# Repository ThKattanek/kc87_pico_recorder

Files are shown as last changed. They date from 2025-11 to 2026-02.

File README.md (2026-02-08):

# KC87 Pico Recorder

KC87 Kassetten-Recorder Emulator mit Raspberry Pi Pico 2 (RP2350).

## Status

**✅ Recording (Aufnahme): Voll funktional**  
❌ Playback (Wiedergabe): Noch nicht implementiert

## Projektstruktur

```
kc87_pico_recorder/
├── firmware/          Pico-Firmware (C, Pico SDK)
├── tools/             Host-Tools (C, Python)
├── hardware/          KiCad-Schaltplan & PCB
├── doc/               Dokumentation
├── PROTOCOL.md        Protokoll-Dokumentation
└── README.md
```

## Hardware

- Raspberry Pi Pico 2 (RP2350) mit Debug-Probe
- **GPIO 3**: Recording-Eingang (`KC87_REC_PICO` — KC87 → Pico)
- **GPIO 2**: Playback-Ausgang (`KC87_PLAY_PICO` — Pico → KC87, noch nicht implementiert)

## Firmware

- Quelldatei: `firmware/kc87_pico_recorder.c`
- Konfiguration: `firmware/config.h`
- Erfasst GPIO-Flanken über Hardware-Interrupts mit Ringpuffer
- Überträgt Samples in einem blockbasierten Binärprotokoll über USB (siehe [PROTOCOL.md](PROTOCOL.md))
- Timing-Auflösung: 1 μs (15-Bit Delta, max. 32767 μs)
- Automatisches Recording-Ende nach 5 s Inaktivität (End-of-Stream-Marker)

### Datenformat (16-Bit Sample)

| Bit 15 | Bit 14–0 |
|---|---|
| Flanke (1 = steigend, 0 = fallend) | Delta-Zeit in Mikrosekunden |

### Block-Protokoll

Die Übertragung erfolgt in Blöcken mit Header- und Sample-Blöcken:

```
[START-BLOCK 0x0000] [BLOCK_TYPE] [PAYLOAD...] [END-BLOCK 0x8000]
```

Details siehe [PROTOCOL.md](PROTOCOL.md).

## Tools

### serial_capture

Empfängt Block-Daten vom Pico und speichert als `.bin` Datei **im kompletten Block-Format** (Header-Block → Sample-Blöcke → End-of-Stream). Optional wird zusätzlich eine WAV-Audiodatei (44.1 kHz, 16-Bit PCM Mono) erzeugt.

```bash
# Nur Binärdaten
./serial_capture -p /dev/ttyACM0 -o aufnahme.bin

# Binärdaten + WAV-Audio
./serial_capture -p /dev/ttyACM0 -o aufnahme.bin -w audio.wav

# Mit spezifischer Baudrate
./serial_capture -p /dev/ttyACM0 -o aufnahme.bin -b 230400
```

Das Recording endet automatisch, sobald die Firmware den End-of-Stream-Marker sendet (5 s Inaktivität).

### serial_transmit

Sendet eine `.bin`-Datei als SLIP-kodierte Samples über eine serielle Verbindung (für zukünftige Playback-Funktion).

```bash
./serial_transmit -p /dev/ttyACM0 -i aufnahme.bin
```

### analyze_bin.py

Analysiert aufgenommene `.bin`-Dateien im Detail.

```bash
python3 tools/analyze_bin.py aufnahme.bin
```

Ausgabe:
- Delta-Zeit-Statistiken (Min/Max/Durchschnitt)
- Flanken-Pattern-Validierung (alternierend steigend/fallend)
- Frequenz-Analyse (Hz, Jitter)
- Overflow- und Ausreißer-Erkennung

### Weitere Python-Tools

- `analyze_first_samples.py` — Analyse der ersten Samples einer Aufnahme
- `bin_to_c_array.py` — Konvertiert `.bin`-Dateien in ein C-Array

## Build

### Firmware

Über die VS Code Pico-Extension oder manuell:

```bash
cd firmware
mkdir -p build && cd build
cmake ..
ninja          # oder: make
```

### Host-Tools (Linux)

```bash
cd tools
cmake -S . -B build
cmake --build build
```

### Host-Tools (Cross-Compilation für Windows)

```bash
cd tools
cmake -S . -B build-windows -DCMAKE_TOOLCHAIN_FILE=mingw-w64-toolchain.cmake
cmake --build build-windows
```

Weitere Build-Details (inkl. Windows nativ) siehe [tools/README.md](tools/README.md).

## Workflow

1. **Pico flashen**: Firmware kompilieren → über Debug-Probe oder UF2 flashen
2. **Recording starten**: `./serial_capture -p /dev/ttyACM0 -o aufnahme.bin`
3. **KC87 Tape abspielen**: GPIO 3 mit KC87-Kassettenausgang verbinden
4. **Recording endet automatisch** nach 5 s Inaktivität
5. **Analyse**: `python3 tools/analyze_bin.py aufnahme.bin`

## Bekannte Einschränkungen

- Playback-Funktionalität ist noch nicht in der Firmware implementiert
- Maximale Delta-Zeit pro Sample: 32767 μs (~32 ms) — längere Pausen werden auf diesen Wert begrenzt
- Bei sehr hoher Flankenfrequenz kann die serielle USB-Übertragung zum Engpass werden

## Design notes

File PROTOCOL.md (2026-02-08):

# KC87 Pico Recorder Transferprotokoll

## Überblick

Das KC87 Pico Recorder System verwendet ein blockbasiertes Binärprotokoll zur Übertragung von GPIO-Ereignissen vom Raspberry Pi Pico an einen Host-Computer über USB-Seriell.

## Protokoll-Konstanten

```c
#define BLOCK_START       0x0000  // Start-Marker eines Blocks
#define BLOCK_END         0x8000  // End-Marker eines Blocks
#define BLOCK_TYPE_HEADER 0x00    // Header-Block (Session-Start)
#define BLOCK_TYPE_SAMPLES 0x01   // Sample-Block (Daten)
#define PROTOCOL_VERSION  0x01    // Protokoll-Version
```

## Sample-Datenformat

Jedes GPIO-Ereignis wird als 16-Bit Wort (Little-Endian) kodiert:

```
Bit 15:    Edge-Typ (1 = steigend, 0 = fallend)
Bit 14-0:  Delta-Zeit in Mikrosekunden (0–32767 µs)
```

**Byte-Anordnung:**
- Byte 0: Niederwertiges Byte (Bits 0–7)
- Byte 1: Höherwertiges Byte (Bits 8–15)

**Dekodierung:**
```c
uint16_t sample = (byte1 << 8) | byte0;
bool rising_edge = (sample & 0x8000) != 0;
uint16_t delta_us = sample & 0x7FFF;
```

## Block-Strukturen

### Header-Block

Signalisiert den Beginn einer Recording-Session:

```
┌──────────────┬────────────┬─────────┬──────────────┐
│ START-BLOCK  │ BLOCK_TYPE │ VERSION │  END-BLOCK   │
│   0x0000     │    0x00    │  0x01   │   0x8000     │
│  (2 Bytes)   │  (1 Byte)  │(1 Byte) │  (2 Bytes)   │
└──────────────┴────────────┴─────────┴──────────────┘
```

**Gesamtgröße:** 6 Bytes

### Sample-Block

Enthält 1–255 GPIO-Samples:

```
┌──────────────┬────────────┬───────┬─────────┬─────────┬───┬───────────┬──────────────┐
│ START-BLOCK  │ BLOCK_TYPE │ COUNT │ SAMPLE0 │ SAMPLE1 │...│ SAMPLEN-1 │  END-BLOCK   │
│   0x0000     │    0x01    │   N   │(2 Bytes)│(2 Bytes)│   │ (2 Bytes) │   0x8000     │
│  (2 Bytes)   │  (1 Byte)  │(1 Byte)│         │         │   │           │  (2 Bytes)   │
└──────────────┴────────────┴───────┴─────────┴─────────┴───┴───────────┴──────────────┘
```

**Gesamtgröße:** 6 + (N × 2) Bytes  
**Maximale Größe:** 6 + (255 × 2) = 516 Bytes

### End-of-Stream

Zwei aufeinanderfolgende `END-BLOCK`-Marker signalisieren das Ende der Aufnahme:

```
┌──────────────┬──────────────┐
│  END-BLOCK   │  END-BLOCK   │
│   0x8000     │   0x8000     │
│  (2 Bytes)   │  (2 Bytes)   │
└──────────────┴──────────────┘
```

## Übertragungsablauf

1. **Session-Start:** Header-Block beim ersten GPIO-Event
2. **Datenübertragung:** Sample-Blöcke mit bis zu 255 Samples
3. **Session-Ende:** End-of-Stream nach 5 Sekunden Inaktivität

## Übertragungsbeispiel

```
# Header-Block (Session-Start)
00 00 00 01 00 80

# Sample-Block mit 3 Samples
00 00 01 03   # START, TYPE=Samples, COUNT=3
  0A 80       # Sample 0: Steigend, 10 µs
  05 00       # Sample 1: Fallend, 5 µs
  0C 80       # Sample 2: Steigend, 12 µs
00 80         # END-BLOCK

# Sample-Block mit 2 Samples
00 00 01 02   # START, TYPE=Samples, COUNT=2
  07 00       # Sample 0: Fallend, 7 µs
  08 80       # Sample 1: Steigend, 8 µs
00 80         # END-BLOCK

# End-of-Stream
00 80         # END-BLOCK
00 80         # END-BLOCK (Stream-Ende)
```

## Serielle Konfiguration

**USB-Seriell Einstellungen:**
- Baudrate: 115200 bps (konfigurierbar)
- Datenbits: 8
- Parität: Keine
- Stoppbits: 1
- Flow Control: Keine

**Timeout:**
- Inaktivitäts-Timeout (Firmware): 5 Sekunden → automatischer End-of-Stream

## Ausgabedatei-Format

Die Host-Software speichert **alle Bytes im Block-Format** in der `.bin`-Datei, beginnend mit dem Header-Block bis einschließlich der End-of-Stream-Marker:

```
# Kompletter Inhalt einer .bin Datei:

[Header-Block: 6 Bytes]
[Sample-Block 1: 6 + N₁×2 Bytes]
[Sample-Block 2: 6 + N₂×2 Bytes]
...
[Sample-Block n: 6 + Nₙ×2 Bytes]
[End-of-Stream: 2 Bytes (0x80 0x00)]
```

Die Datei kann direkt für Playback verwendet oder mit den gleichen Parsing-Regeln analysiert werden, die in diesem Dokument beschrieben sind.

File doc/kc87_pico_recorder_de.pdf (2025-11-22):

# KC87 Pico Recorder

von Thorsten Kattanek, letzte Änderung 22.11.2025

## Inhaltsverzeichnis

Wie können wir das Signal so umwandeln das wir es mit dem Pico empfangen und auswerten

## Vorwort

Das Projekt entstand aus meinen Nachforschungen zum KC87. Ich habe mir 2025 einen KC87 zugelegt. Auch recht Preiswert, mit 100€ zu dieser Zeit. So oft findet man diese leider nicht mehr. Die Community ist natürlich deutlich kleiner als die der Commodore Liebhaber. Aber es gibt doch ein paar nette Internetseiten die ich hier mal Aufzähle.

https://hc-ddr.hucki.net/wiki/doku.php
https://www.sax.de/~zander/
https://floooh.github.io/virtualkc/

Das sind schon recht gute Quellen wenn man sich mit alten DDR Computern beschäftigen möchte. In dieser Dokumentation werde ich auch alle Technischen Details was die Elektronik und auch die Programmierung der Firmware und auch der Software für den PC wenn entspr. Tools von mir erstellt werden behandeln. Ich hoffe das am Ende ein nützliches, kleines Stück Hardware raus kommt womit man den KC87 erweitern kann. Am Ende würde ich dieses Projekt dann, mit in das ThePicoRetroTape (https://github.com/ThKattanek/the_pico_retro_tape) Projekt mit einfließen lassen. Aber das erst dann, wenn hier alles so funktioniert wie ich mir das vorstelle.

## Was ist der „KC87 Pico Recorder“ ?

Mit dem Pico Recorder soll am Ende der „alte“ Kassettenrecorder ersetzt werden. Wie der Name schon erahnen lässt, basiert der „neue“ Recorder auf den Raspberry Pi Pico Borad.

## Technisches „Bla Bla“

## Wie sieht das Signal aus wenn es per „CSAVE“ aus dem KC87 kommt?

Das Kassetten Signal wird aus der rechten Seite des KC87 entnommen. Dort befindet sich eine Buchse wo man früher den Kassettenrecorder angeschlossen hat. Hier ein Bild wo man genau sieht wie diese Buchse standardmäßig belegt ist.

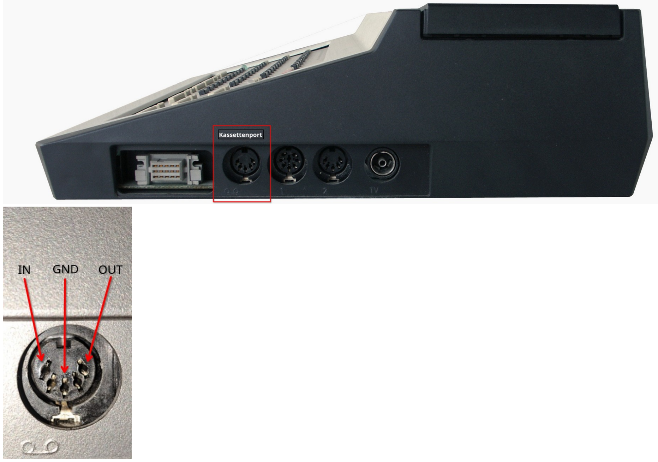
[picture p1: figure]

Das Signal was bei OUT raus kommt ist ein Rechtecksignal mit einer Amplitude von ca. 130-150mV. Laut Robotron ist das eine Frequenzmodulation bzw. Frequenzumtastung (FSK). Das ganze sieht mit dem Oszi so aus. Dieses Signal wird so ausgegeben wenn ich „CSAVE“ gleich nach dem Start eingeben und 2x mit Enter bestätige. Das ist nicht im BASIC ! Hier bleibt das Signal dauerhaft an.

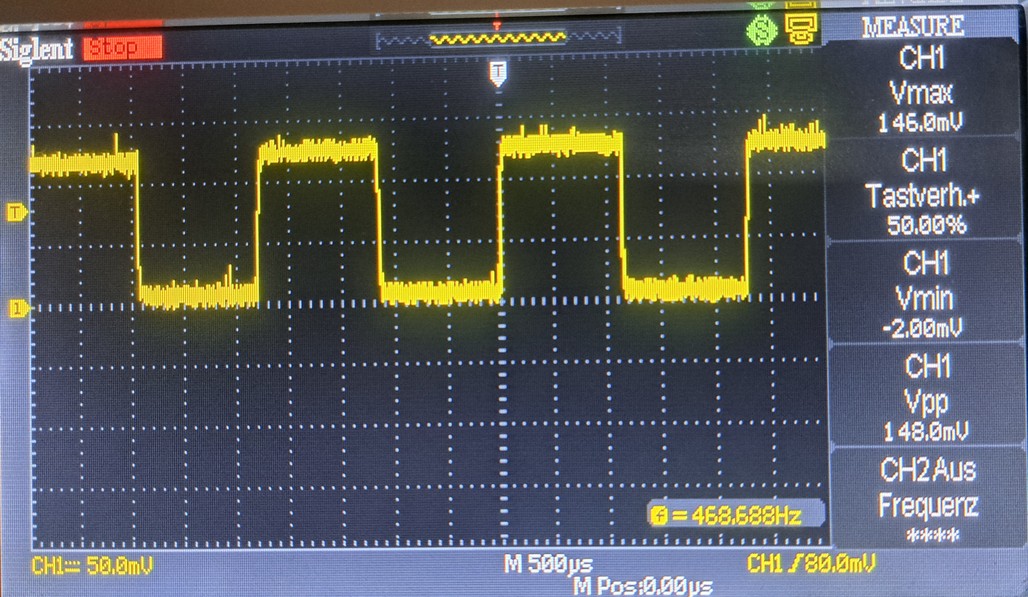
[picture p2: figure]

## Wie können wir das Signal so umwandeln das wir es mit dem Pico empfangen und auswerten können?

Ich bin da sehr optimistisch und habe mich für folgende Schaltung entschieden. Ich verwende dazu einen Komparator, der mir das Signal Phasengleich auf das Level bringt welches ich benötige. In diesem Fall ein Logik Level von 3,3V um direkt an den Pico damit zu gehen.

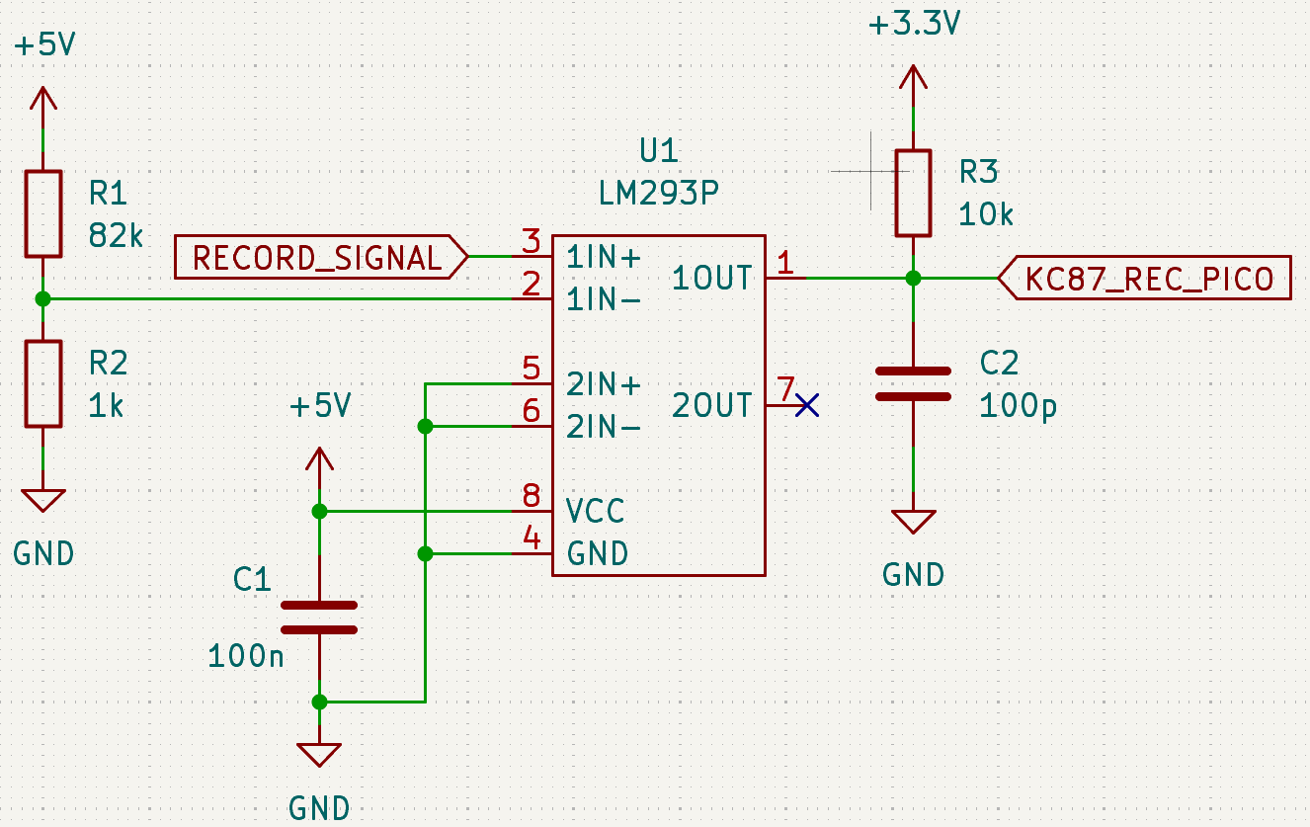
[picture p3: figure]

Hier eine kurze Beschreibung der Schaltung. Im Mittelpunkt ist der Komparator LM293P. Dieser hat als Ausgang einen Open-Colector. Somit sind wir dort schon mal frei um uns unser Ausgangssignal vom Pegel her selber zu bestimmen. Am Ausgang haben wir einen 10KΩ Pullup Widerstand R3. Außerdem ist zwischen dem Ausgang und GND ein 100pF Kondensator um Spannungsspitzen zu minimieren. Das Record Signal vom KC87 kommt direkt auf dem Negativen Eingang des Komparators. Das Vergleichssignal muss genau in der Mitte liegen der ca. 130mV. Das erreichen wir mit dem Spannungsteiler R1/R2. Die Eingänge des unbenutzten Komparators werden auf GND gelegt. Hier das Ausgangssignal „KC87_REC_PICO“.

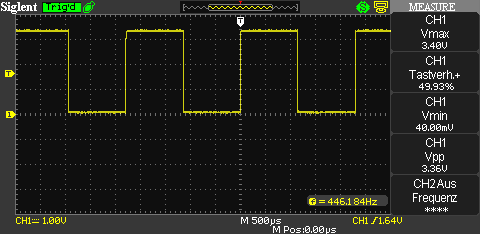
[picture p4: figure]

## Wie kommen wir an die Bits und Bytes?

Jetzt wo wir ein vernünftige Digitales Signal haben, können wir uns nun anschauen wie in diesem Datenstrom die Daten codiert sind.

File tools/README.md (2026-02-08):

# KC87 Pico Recorder Tools

Build the host CLI tools (Windows/Linux) from this folder.

This directory contains two tools:
- `serial_capture`: Captures data from KC87 via Pico (KC87 → Pico → PC)
- `serial_transmit`: Transmits data to KC87 via Pico (PC → Pico → KC87)

## Build (CMake)

### Linux

```bash
cmake -S . -B build
cmake --build build
```

### Cross-Compilation for Windows (on Ubuntu/Kubuntu)

To build Windows executables from Linux, you need the MinGW-w64 cross-compiler:

#### 1. Install MinGW-w64 cross-compiler
```bash
sudo apt update
sudo apt install mingw-w64 cmake
```

#### 2. Create a CMake toolchain file
Create a file called `mingw-w64-toolchain.cmake` in the tools directory:

```cmake
# mingw-w64-toolchain.cmake
set(CMAKE_SYSTEM_NAME Windows)
set(CMAKE_SYSTEM_PROCESSOR x86_64)

# Specify the cross compiler
set(CMAKE_C_COMPILER x86_64-w64-mingw32-gcc)
set(CMAKE_CXX_COMPILER x86_64-w64-mingw32-g++)
set(CMAKE_RC_COMPILER x86_64-w64-mingw32-windres)

# Where to find libraries and headers
set(CMAKE_FIND_ROOT_PATH /usr/x86_64-w64-mingw32)

# Search for programs in the build host directories
set(CMAKE_FIND_ROOT_PATH_MODE_PROGRAM NEVER)
# Search for libraries and headers in the target environment
set(CMAKE_FIND_ROOT_PATH_MODE_LIBRARY ONLY)
set(CMAKE_FIND_ROOT_PATH_MODE_INCLUDE ONLY)
```

#### 3. Cross-compile for Windows
```bash
# Create build directory for Windows
cmake -S . -B build-windows -DCMAKE_TOOLCHAIN_FILE=mingw-w64-toolchain.cmake
cmake --build build-windows

# For 32-bit Windows (optional)
# Use i686-w64-mingw32-gcc instead and adjust toolchain file accordingly
```

#### 4. Result
The Windows executables will be created as:
- `build-windows/serial_capture.exe`
- `build-windows/serial_transmit.exe`

#### Alternative: One-liner without toolchain file
```bash
cmake -S . -B build-windows \
  -DCMAKE_SYSTEM_NAME=Windows \
  -DCMAKE_C_COMPILER=x86_64-w64-mingw32-gcc \
  -DCMAKE_CXX_COMPILER=x86_64-w64-mingw32-g++
cmake --build build-windows
```

### Windows (from scratch)

For a fresh Windows installation, you need to install the following tools:

#### 1. Install Visual Studio Community (free)
- Download from: https://visualstudio.microsoft.com/downloads/
- During installation, select "Desktop development with C++"
- This includes the MSVC compiler and Windows SDK

#### 2. Install CMake
- Download from: https://cmake.org/download/
- Choose "Windows x64 Installer"
- During installation, select "Add CMake to the system PATH for all users"

#### 3. Install Git (optional, if you want to clone the repository)
- Download from: https://git-scm.com/download/win
- Use default settings during installation

#### 4. Build the project
Open **Command Prompt** or **PowerShell** and navigate to the tools directory:

```cmd
cd path\to\kc87_pico_recorder\tools
cmake -S . -B build
cmake --build build --config Release
```

Alternatively, you can use **Visual Studio Developer Command Prompt** (recommended):
- Open "Developer Command Prompt for VS 2022" from Start Menu
- Navigate to the tools directory
- Run the same cmake commands

#### 5. Alternative: Using Visual Studio IDE
You can also open the project directly in Visual Studio:
- Open Visual Studio
- File → Open → CMake...
- Select the `CMakeLists.txt` in the tools directory
- Visual Studio will automatically configure the project
- Build → Build All

The executables will be:
- Linux: `build/serial_capture` and `build/serial_transmit`
- Windows: `build/Debug/serial_capture.exe` and `build/Debug/serial_transmit.exe` (or `build/Release/...`)

## Usage

### Recording (KC87 → Pico → PC)

```bash
serial_capture -p <port> -o <out_file> [-b baud] [-w wav_file]
```

Parameters:
- `-p <port>`: Serial port (e.g., /dev/ttyACM0, COM3)
- `-o <out_file>`: Binary output file
- `-b <baud>`: Baud rate (default: 115200)
- `-w <wav_file>`: Optional WAV output file

Examples:

```bash
# Basic usage - capture only binary data
serial_capture -p /dev/ttyACM0 -o capture.bin -b 115200

# Capture both binary data and WAV audio
serial_capture -p /dev/ttyACM0 -o capture.bin -b 115200 -w audio.wav
```

```powershell
# Windows examples
serial_capture -p COM6 -o capture.bin -b 115200
serial_capture -p COM6 -o capture.bin -b 115200 -w audio.wav
```

### Playback (PC → Pico → KC87)

```bash
serial_transmit -p <port> -i <input_file> [-b baud]
```

Parameters:
- `-p <port>`: Serial port (e.g., /dev/ttyACM0, COM3)
- `-i <input_file>`: Binary input file to transmit
- `-b <baud>`: Baud rate (default: 115200)

Examples:

```bash
# Transmit previously captured data
serial_transmit -p /dev/ttyACM0 -i capture.bin -b 115200
```

```powershell
# Windows example
serial_transmit -p COM6 -i capture.bin -b 115200
```

## Output Format

The output file contains raw 2-byte payloads per event (little-endian). Each payload word is:

- Bit 15: `edge` (1=rising, 0=falling)
- Bits 14..0: `delta_us` (0..32767)

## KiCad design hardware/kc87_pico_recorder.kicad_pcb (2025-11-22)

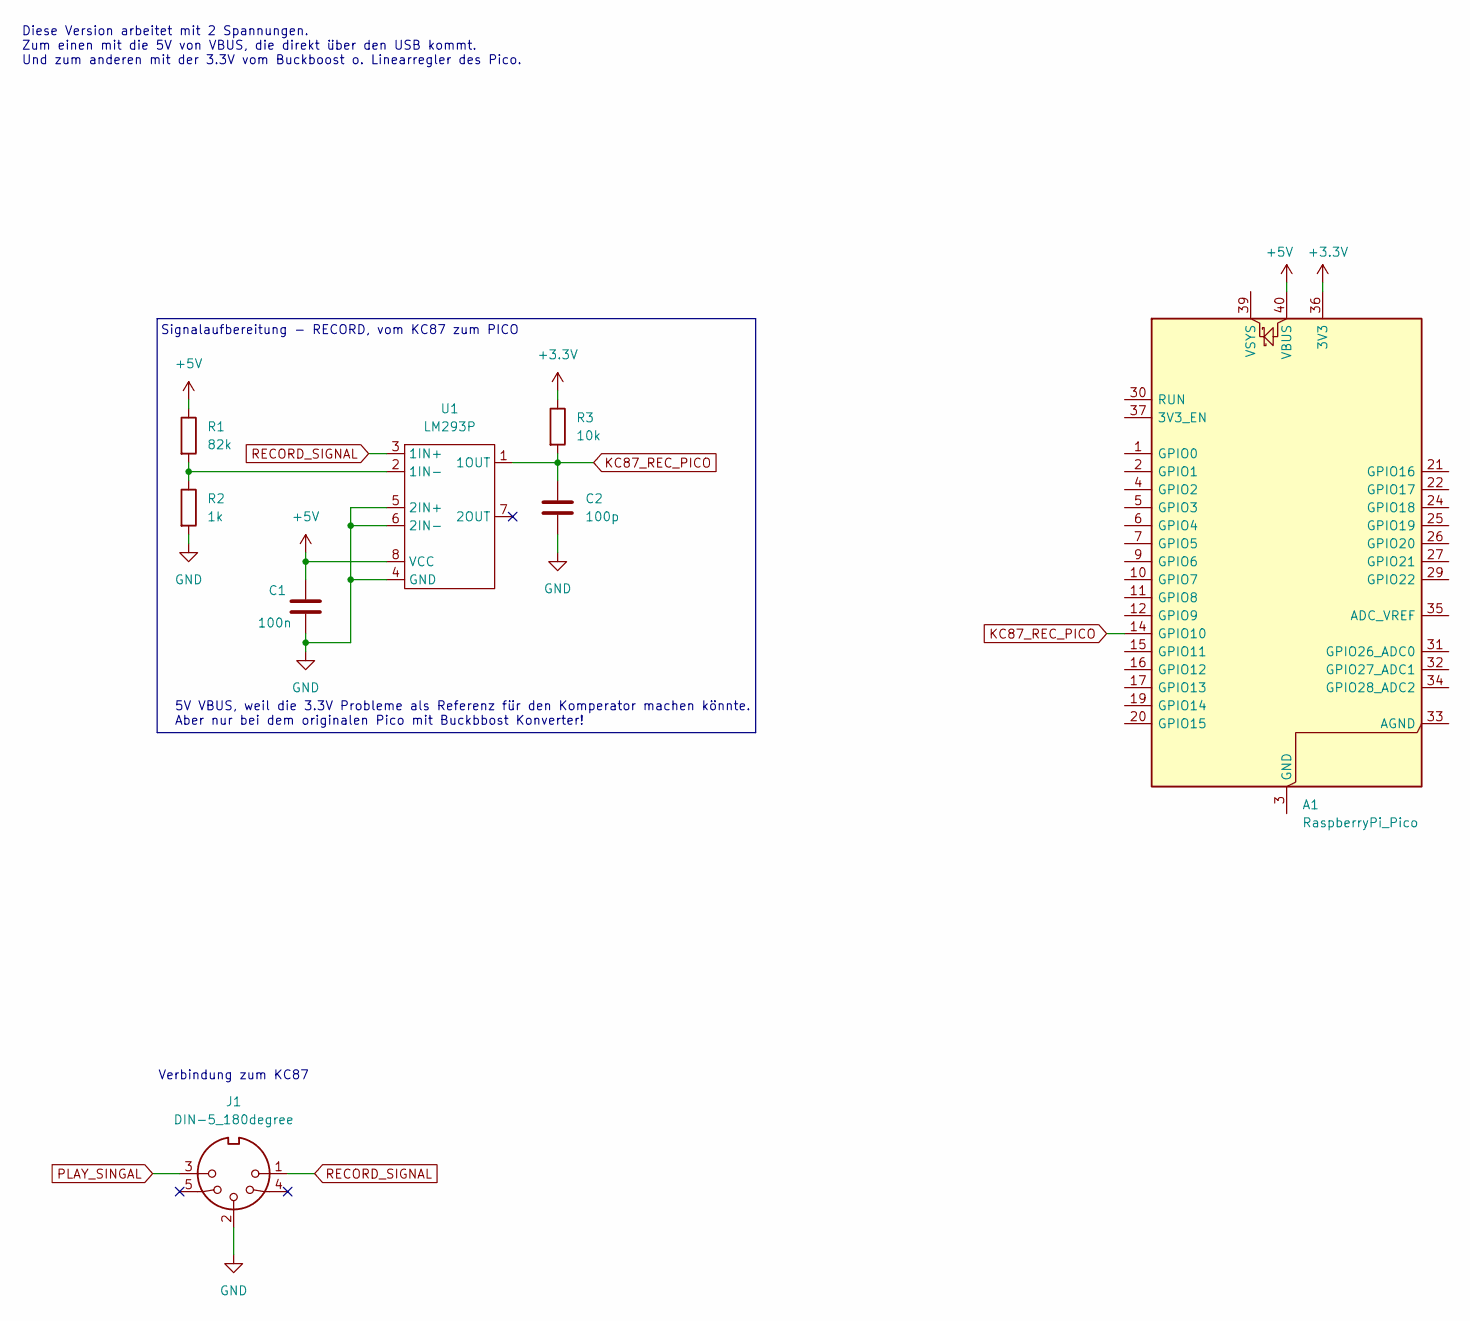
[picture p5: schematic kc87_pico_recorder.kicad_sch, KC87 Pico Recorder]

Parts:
A1: RaspberryPi_Pico; RaspberryPi_Pico_Common_SMD
C1: 100n; C_0805_2012Metric_Pad1.18x1.45mm_HandSolder
C2: 100p; C_0805_2012Metric_Pad1.18x1.45mm_HandSolder
J1: DIN-5_180degree; din-5
R1: 82k; R_0805_2012Metric_Pad1.20x1.40mm_HandSolder
R2: 1k; R_0805_2012Metric_Pad1.20x1.40mm_HandSolder
R3: 10k; R_0805_2012Metric_Pad1.20x1.40mm_HandSolder
U1: LM293P; DIP-8_W7.62mm_SMDSocket_SmallPads

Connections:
+3.3V: A1.36 (3V3), R3.1
+5V: A1.40 (VBUS), C1.1, R1.1, U1.8 (VCC)
GND: C1.2, C2.2, J1.2, R2.2, U1.4 (GND), U1.5 (2IN+), U1.6 (2IN-)
KC87_REC_PICO: A1.14 (GPIO10), C2.1, R3.2, U1.1 (1OUT)
unnamed: A1.3 (GND), A1.8 (GND), A1.13 (GND), A1.18 (GND), A1.23 (GND), A1.28 (GND), A1.38 (GND)
unnamed: R1.2, R2.1, U1.2 (1IN-)
PLAY_SINGAL: J1.3
RECORD_SIGNAL: J1.1, U1.3 (1IN+)

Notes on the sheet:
Verbindung zum KC87
5V VBUS, weil die 3.3V Probleme als Referenz für den Komperator machen könnte. Aber nur bei dem originalen Pico mit Buckbbost Konverter!
Diese Version arbeitet mit 2 Spannungen. Zum einen mit die 5V von VBUS, die direkt über den USB kommt. Und zum anderen mit der 3.3V vom Buckboost o. Linearregler des Pico.
Signalaufbereitung - RECORD, vom KC87 zum PICO

Board: 2 copper layers, 8 parts (0 on the bottom side), 7 nets, no tracks yet.

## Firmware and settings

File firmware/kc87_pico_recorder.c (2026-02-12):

#include <stdio.h>
#include "pico/stdlib.h"
#include "pico/stdio_usb.h"
#include "hardware/gpio.h"
#include "hardware/timer.h"
#include "hardware/uart.h"
#include "config.h"

// UART Configuration (Debug Probe UART Bridge)
// UART0: TX = GPIO0, RX = GPIO1
#define UART_ID uart0
#define UART_TX_PIN 0
#define UART_RX_PIN 1
#define UART_BAUD_RATE 115200

// Serial Data Encoding
// Data format: 16-bit sample where MSB is edge type (1=Rising, 0=Falling) and lower 15 bits are delta in microseconds
// Example: 0x800A = Rising edge with 10 μs delta, 0x0005 = Falling edge with 5 μs delta
// Data sent in an Block-Format with max 255 samples per block (510 bytes + 5 bytes overhead) for efficient transmission.
// Block format: [START-BLOCK][SAMPLE_COUNT][SAMPLE0][SAMPLE1][SAMPLE2]...[SAMPLEN][END-BLOCK]
// START-BLOCK = 0x0000, END-BLOCK = 0x8000

// Header Block structure:
// 0x0000 - 0x0000 [2 Bytes] START-BLOCK
// 0x0002 - 0x00   [1 Byte]  BLOCK_TYPE (0x00 = Header-Block)
// 0x0003 - 0x01   [1 Byte]  VERSION (0x01)
// 0x0004 - 0x8000 [2 Bytes] END-BLOCK (0x8000)

// Sample Block structure (version 0x01):
// 0x0000 - 0x0000 [2 Bytes] START-BLOCK
// 0x0002 - 0x..   [1 Byte] BLOCK_TYPE (0x01 = Sample-Block
// 0x0003 - 0x..   [1 Byte] SAMPLE_COUNT (N, max 255)
// 0x0004 - 0x..   [2*N Bytes] SAMPLE0, SAMPLE1, ..., SAMPLEN-1
// 0x..   - 0x8000 [2 Bytes] END-BLOCK (0x8000)

// End of Block is always signaled by the fixed END-BLOCK marker (0x8000). The number of samples is specified in the SAMPLE_COUNT field.
// End of Stream is signaled by consecutive 0x8000 marker 0x8000 

// Recording variables
volatile uint32_t last_timestamp = 0;
volatile uint32_t timestamp = 0;
volatile bool recording = false;
volatile bool send_header_flag = false;
volatile uint16_t sample_count = 0;
volatile uint16_t sample_buffer[256]; // Buffer for 256 samples (512 bytes)
volatile uint16_t ring_buffer[1024]; // Ring buffer for 1024 samples
volatile uint16_t ring_head = 0;
volatile uint16_t ring_tail = 0;

#define RECORDING_TIMEOUT_US 5 * 1000 * 1000 // 5s inactivity timeout

void send_header_block()
{
    printf("[DEBUG] Sending header block\n");
    // Header block format:
    // START-BLOCK (0x0000), BLOCK_TYPE (0x00), VERSION (0x01), END-BLOCK (0x8000)
    uint8_t header_buf[6] = {
        0x00, 0x00,  // START-BLOCK
        0x00,        // BLOCK_TYPE: Header-Block
        0x01,        // VERSION: 0x01
        0x00, 0x80   // END-BLOCK
    };
    uart_write_blocking(UART_ID, header_buf, 6);
}
    
void gpio_callback(uint gpio, uint32_t events)
{
    if (gpio != GPIO_RECORD_PIN)
        return;

    if (!recording) 
    {
        // Start recording on first trigger
        recording = true;
        send_header_flag = true; // Flag to send header block on next sample
        printf("[DEBUG] Recording started\n");
    }

    timestamp = time_us_32();
    
    // Calculate delta from last timestamp
    uint32_t delta_us;
    if (timestamp >= last_timestamp) 
    {
        delta_us = timestamp - last_timestamp;
    } else 
    {
        // Timer overflow handling 
        delta_us = (UINT32_MAX - last_timestamp) + timestamp + 1;
    }
    
    // Limit delta to 15-bit range (32767 μs = ~32ms max)
    if (delta_us > 32767) 
    {
        delta_us = 32767;
    }
    
    // Encode: Edge-Bit in MSB (Rise=1, Fall=0), Delta in lower 15 bits
    uint16_t edge_bit = (events & GPIO_IRQ_EDGE_RISE) ? 0x8000 : 0x0000;
    uint16_t next_head = (ring_head + 1) % 1024;
    if (next_head == ring_tail) {
        // Drop oldest sample on overflow to keep ring buffer consistent.
        ring_tail = (ring_tail + 1) % 1024;
    }
    ring_buffer[ring_head] = (uint16_t)delta_us | edge_bit;
    ring_head = next_head;
    
    last_timestamp = timestamp;
}

int main() 
{   
    // Initialize ONLY USB stdio for debug output (not UART!)
    stdio_usb_init();

    sleep_ms(1000); // Short delay to ensure USB connection is established before printing debug messages

    printf("KC87 Pico Recorder - ");
    printf("Version: " FW_VERSION_STRING "\n");
    
    // Initialize UART for binary data stream (Debug Probe UART or FT232L)
    uart_init(UART_ID, UART_BAUD_RATE);
    gpio_set_function(UART_TX_PIN, GPIO_FUNC_UART);
    gpio_set_function(UART_RX_PIN, GPIO_FUNC_UART);
    
    // GPIO-Pins konfigurieren (nur Recording)
    gpio_init(GPIO_RECORD_PIN);
    gpio_set_dir(GPIO_RECORD_PIN, GPIO_IN);
    
    // IRQ für Recording-GPIO konfigurieren
    timestamp = last_timestamp = time_us_32();
    sleep_us(2);
    gpio_set_irq_enabled_with_callback(GPIO_RECORD_PIN, GPIO_IRQ_EDGE_RISE | GPIO_IRQ_EDGE_FALL, true, gpio_callback);

    printf("[DEBUG] KC87 Pico Recorder started\n");
    printf("[DEBUG] UART: %d baud on GPIO%d/GPIO%d\n", UART_BAUD_RATE, UART_TX_PIN, UART_RX_PIN);
    printf("[DEBUG] Waiting for signal on GPIO%d...\n", GPIO_RECORD_PIN);

    uint32_t delta_us;
    uint32_t last_timeout_check = 0;

    // Hauptschleife
    while (true) 
    {
        if(send_header_flag) 
        {
            send_header_block();
            send_header_flag = false;
            sample_count = 0; // Reset sample count for new recording session
            last_timeout_check = time_us_32(); // Reset timeout check timer
        }

        if(recording)
        {
            // Drain ring buffer in batch (up to 255 samples at once)
            while (ring_tail != ring_head && sample_count < 255) 
            {
                sample_buffer[sample_count++] = ring_buffer[ring_tail];
                ring_tail = (ring_tail + 1) % 1024;
            }

            // If we have 255 samples, send a block
            if (sample_count == 255) 
            {
                    // Send block format:
                    // START-BLOCK (0x0000), BLOCK_TYPE (0x01), SAMPLE_COUNT (0xFF), SAMPLES..., END-BLOCK (0x8000)
                    // Total: 4 bytes header + 510 bytes samples + 2 bytes end = 516 bytes
                    uint8_t block_buf[516];
                    block_buf[0] = 0x00; // START-BLOCK LSB
                    block_buf[1] = 0x00; // START-BLOCK MSB
                    block_buf[2] = 0x01; // BLOCK_TYPE: Sample-Block
                    block_buf[3] = 0xFF; // SAMPLE_COUNT: 255

                    for (int i = 0; i < 255; i++) 
                    {
                        block_buf[4 + i * 2] = sample_buffer[i] & 0xFF;       // Sample LSB
                        block_buf[4 + i * 2 + 1] = (sample_buffer[i] >> 8) & 0xFF; // Sample MSB
                    }

                    block_buf[514] = 0x00; // END-BLOCK LSB
                    block_buf[515] = 0x80; // END-BLOCK MSB
                    
                    uart_write_blocking(UART_ID, block_buf, 516);
                    printf("[DEBUG] Sent data block (255 samples)\n");

                    sample_count = 0; // Reset sample count for next block
            }
            
            // Check timeout periodically (every 100ms) even if ring buffer is not empty
            uint32_t current_time = time_us_32();
            uint32_t time_since_last_check;
            if (current_time >= last_timeout_check) {
                time_since_last_check = current_time - last_timeout_check;
            } else {
                time_since_last_check = (UINT32_MAX - last_timeout_check) + current_time + 1;
            }
            
            if (time_since_last_check >= 100000) // Check every 100ms
            {
                last_timeout_check = current_time;
                
                // Calculate delta from last edge event to check for inactivity
                // Handle timer overflow
                if (current_time >= timestamp) {
                    delta_us = current_time - timestamp;
                } else {
                    delta_us = (UINT32_MAX - timestamp) + current_time + 1;
                }

                if(delta_us > RECORDING_TIMEOUT_US) // inactivity timeout
                {
                    if(sample_count > 0) // If there are remaining samples, send them in a final block
                    {
                        // Send remaining samples in a final block
                        uint8_t final_block_buf[4 + sample_count * 2 + 2];
                        final_block_buf[0] = 0x00; // START-BLOCK LSB
                        final_block_buf[1] = 0x00; // START-BLOCK MSB
                        final_block_buf[2] = 0x01; // BLOCK_TYPE: Sample-Block
                        final_block_buf[3] = sample_count & 0xFF; // SAMPLE_COUNT

                        for (int i = 0; i < sample_count; i++) 
                        {
                            final_block_buf[4 + i * 2] = sample_buffer[i] & 0xFF; // Sample LSB
                            final_block_buf[4 + i * 2 + 1] = (sample_buffer[i] >> 8) & 0xFF; // Sample MSB
                        }

                        final_block_buf[4 + sample_count * 2] = 0x00; // END-BLOCK LSB
                        final_block_buf[4 + sample_count * 2 + 1] = 0x80; // END-BLOCK MSB
                        
                        uart_write_blocking(UART_ID, final_block_buf, 4 + sample_count * 2 + 2);
                        printf("[DEBUG] Sent final block (%d samples)\n", sample_count);
                    }
                    
                    // Send End of Stream marker (two consecutive END-BLOCKs)
                    uint8_t end_stream[2] = {0x00, 0x80};
                    uart_write_blocking(UART_ID, end_stream, 2);
                    printf("[DEBUG] Recording stopped (timeout after %d us inactivity)\n", delta_us);

                    recording = false; // Stop recording until next trigger
                    sample_count = 0; // Reset sample count
                    ring_head = ring_tail = 0; // Clear ring buffer
                }
            }
        }
        
        if (!recording || ring_tail == ring_head) {
            sleep_us(100); // Short sleep to service USB stack (printf) when no data pending
        }
    }

    return 0;
}

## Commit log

2025-11-22 Add initial project files and setup for KC87 Pico Recorder
    - Create README with project structure and ToDo list
    - Add .gitignore for build artifacts
    - Configure VSCode settings and tasks for building and debugging
    - Implement main application logic in main.c
    - Include CMake configuration for project setup
    - Import Raspberry Pi Pico SDK for development
2025-11-22 added the hardware directory with the kicad project with schematic
    [kc87_pico_recorder.kicad_pcb, kc87_pico_recorder.kicad_sch]
2025-11-22 Refactor CMakeLists.txt to use consistent project name and board type
2025-11-23 Refactor project structure: replace main.c with kc87_pico_recorder.c, update CMakeLists.txt, and add config.h for GPIO configuration
    [kc87_pico_recorder.kicad_sch]
2026-01-31 firmware: hhe “tools” folder has been moved.
2026-02-03 Hardware: change kc87_pico_recorder.kicad_sch (new amplifier)
    [kc87_pico_recorder.kicad_sch]
2026-10-22 wip: hardware state saving for beginning a new schematic
2026-10-24 wip: new circuit for signal from kc87 to pico (a program save)
2026-10-24 wip: new pc command tool for analytics the icomming datas from the pico
2026-10-24 add block decoder and TAP export to kc87tool
    - kc87tool: new "decode" command (bytes, blocks, checksum, BASIC program
    name), TAP export for JKCEMU, remove SVG export
    - README/doc: describe tape format, new record circuit and PC tool
    - schematic: update note for the record circuit (no potentiometer anymore)
2026-10-24 doc: update record signal oscilloscope picture
    - replace scope picture with measurement of the new record circuit
    (Vmax 2.44 V at KC87_REC_PICO)
    - add caption with measured values below the picture
    - regenerate PDF
2026-10-25 wip: added a play testprog and new circuit for signals to kc87
2026-10-25 wip: update schematic, R5 180 Ohm to 150 Ohm
2026-10-25 add playback and WAV import
    Firmware:
    - pulse_out.pio: PIO program that outputs the pulse durations on GP3
    - main.c: new command 'P', ring buffer with prefill, underrun/abort status
    kc87tool:
    - encode: TAP -> pulse sequence (Vorton, separators, trailing Vorton)
    - fromwav: WAV -> pulse sequence (zero crossings with hysteresis)
    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
